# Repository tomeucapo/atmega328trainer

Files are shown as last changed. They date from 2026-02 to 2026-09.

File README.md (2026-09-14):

# ATMega328P Trainer

Basic board for practicing with the ATMega328P microcontroller. It includes an optocoupled input designed to connect pulse sensors at different voltages, such as an anemometer that operates at 24VDC. It also includes a USB-to-serial adapter that allows you to work with the ATMega's UART.

https://www.pcbway.com/project/shareproject/Anemometer_with_ATMega128P_fbefd825.html

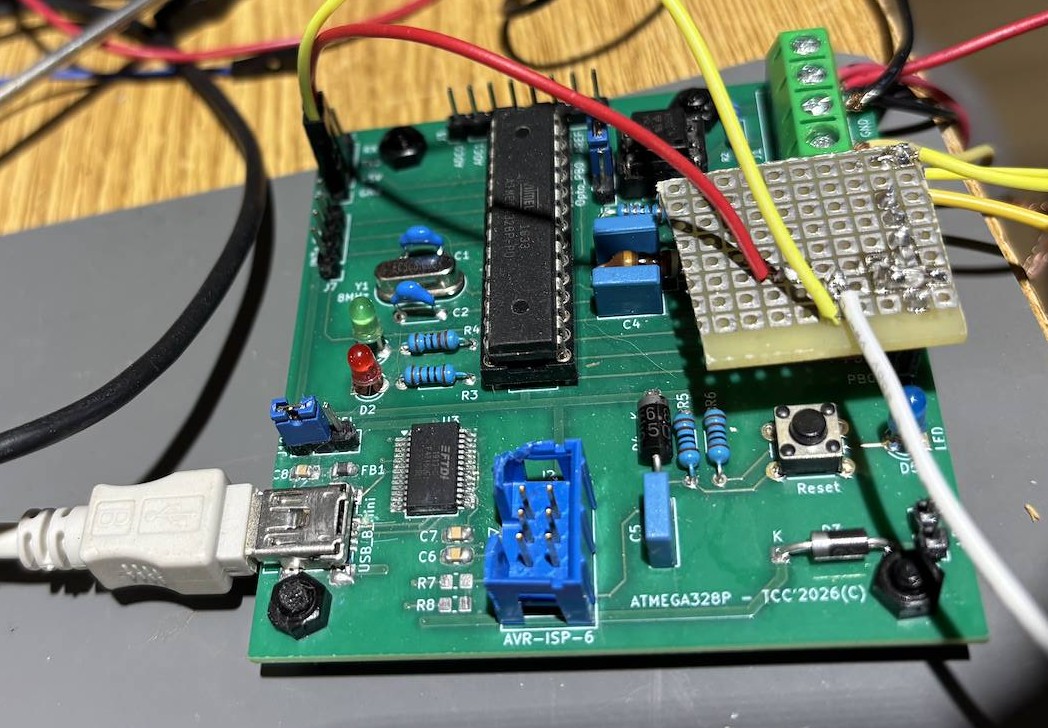
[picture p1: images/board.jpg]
Board


## Weather station base

This first version supports wind, rain and temperature sensors can read from USB port with simple commands:

```
@STAT_TEMP
@STAT_RAIN
@STAT_ANEMO
```

Also can reset RAIN counter with @RESET_RAIN.

Temperature sensor is digital serial sensor DS18B20, one bit data serial contected to PB2 port.

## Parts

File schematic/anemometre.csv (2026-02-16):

Reference | Qty | Value | DNP | Exclude from BOM | Exclude from Board | Footprint | Datasheet | MPN | Farnell | Farell
C1,C2 | 2 | 33pF |  |  |  | Capacitor_THT:C_Disc_D4.3mm_W1.9mm_P5.00mm | ~ |  | 4143719
C3,C4,C5 | 3 | 100nF |  |  |  | Capacitor_THT:C_Disc_D7.0mm_W2.5mm_P5.00mm | ~ | CK05BX104K | 1740547
C6,C7,C8 | 3 | 100nF |  |  |  | Capacitor_SMD:C_0805_2012Metric_Pad1.18x1.45mm_HandSolder | ~ | MC0805B104M160CT | 1708714
D1,D2,D5 | 3 | LED |  |  |  | LED_THT:LED_D3.0mm | ~ |  | 2251291,2984088,3777906
D3 | 1 | 1N5819 |  |  |  | Diode_THT:D_DO-35_SOD27_P10.16mm_Horizontal | http://www.vishay.com/docs/88503/1n4001.pdf | 1N5819 | 2677422
D4 | 1 | P6KE6.8A |  |  |  | Diode_THT:D_DO-35_SOD27_P10.16mm_Horizontal | http://www.vishay.com/docs/88503/1n4001.pdf | P6KE6.8A | 3288608
FB1 | 1 | 33 µH, 2.2 ohm |  |  |  | Inductor_SMD:L_0805_2012Metric | ~ | MLF1608C330KTD25 | 3648165
J1 | 1 | Anemometre |  |  |  | TerminalBlock_Phoenix:TerminalBlock_Phoenix_MKDS-1,5-4-5.08_1x04_P5.08mm_Horizontal | ~
J2 | 1 | AVR-ISP-6 |  |  |  | Connector_IDC:IDC-Header_2x03_P2.54mm_Vertical | ~ | 75869-131LF | 2293757
J3 | 1 | PORT_C_ADC |  |  |  | Connector_PinHeader_2.54mm:PinHeader_1x08_P2.54mm_Vertical | ~
J4 | 1 | PORT_B |  |  |  | Connector_PinHeader_2.54mm:PinHeader_1x06_P2.54mm_Vertical | ~
J5 | 1 | Opto_PB0 |  |  |  | Connector_PinHeader_2.54mm:PinHeader_1x03_P2.54mm_Vertical | ~
J6 | 1 | TTL Serial |  |  |  | Connector_PinHeader_2.54mm:PinHeader_1x04_P2.54mm_Vertical | ~
J7 | 1 | INTs/Ts |  |  |  | Connector_PinHeader_2.54mm:PinHeader_1x04_P2.54mm_Vertical | ~
J8 | 1 | USB_B_Mini |  |  |  | Connector_USB:USB_Mini-B_Wuerth_65100516121_Horizontal | ~ | 10033526N3212LF | 2813789
J9 | 1 | +5VDC |  |  |  | Connector_PinHeader_2.54mm:PinHeader_1x02_P2.54mm_Vertical | ~
J10 | 1 | PWR_SEL |  |  |  | Connector_PinHeader_2.54mm:PinHeader_1x03_P2.54mm_Vertical | ~
L1 | 1 | 10uH |  |  |  | Inductor_THT:L_Axial_L5.3mm_D2.2mm_P10.16mm_Horizontal_Vishay_IM-1 | ~ | 77F100K-TR-RC | 2924990
R1 | 1 | 10K |  |  |  | Resistor_THT:R_Axial_DIN0204_L3.6mm_D1.6mm_P7.62mm_Horizontal | ~ |  | 9339060
R2 | 1 | 4.7K |  |  |  | Resistor_THT:R_Axial_DIN0204_L3.6mm_D1.6mm_P7.62mm_Horizontal | ~ |  | 9339540
R3,R4,R5,R6 | 4 | 1K |  |  |  | Resistor_THT:R_Axial_DIN0204_L3.6mm_D1.6mm_P7.62mm_Horizontal | ~ |  | 9339051
R7,R8 | 2 | 100_NM |  |  |  | Resistor_SMD:R_0805_2012Metric_Pad1.20x1.40mm_HandSolder | ~
SW1 | 1 | Reset |  |  |  | Button_Switch_THT:SW_PUSH_6mm_H5mm | ~
U1 | 1 | ATmega328P-P |  |  |  | Package_DIP:DIP-28_W7.62mm | http://ww1.microchip.com/downloads/en/DeviceDoc/ATmega328_P%20AVR%20MCU%20with%20picoPower%20Technology%20Data%20Sheet%2040001984A.pdf | ATMEGA328P-PU | 1715487
U2 | 1 | 4N25 |  |  |  | Package_DIP:DIP-6_W7.62mm | https://www.vishay.com/docs/83725/4n25.pdf | CNY75A | 1045402
U3 | 1 | FT232RL |  |  |  | Package_SO:SSOP-28_5.3x10.2mm_P0.65mm | https://www.ftdichip.com/Support/Documents/DataSheets/ICs/DS_FT232R.pdf | FT232RL-REEL | 1146032
Y1 | 1 | 8MHz |  |  |  | Crystal:Crystal_HC49-U_Vertical | ~ | ECS-080-20-4X-DU | 4076777

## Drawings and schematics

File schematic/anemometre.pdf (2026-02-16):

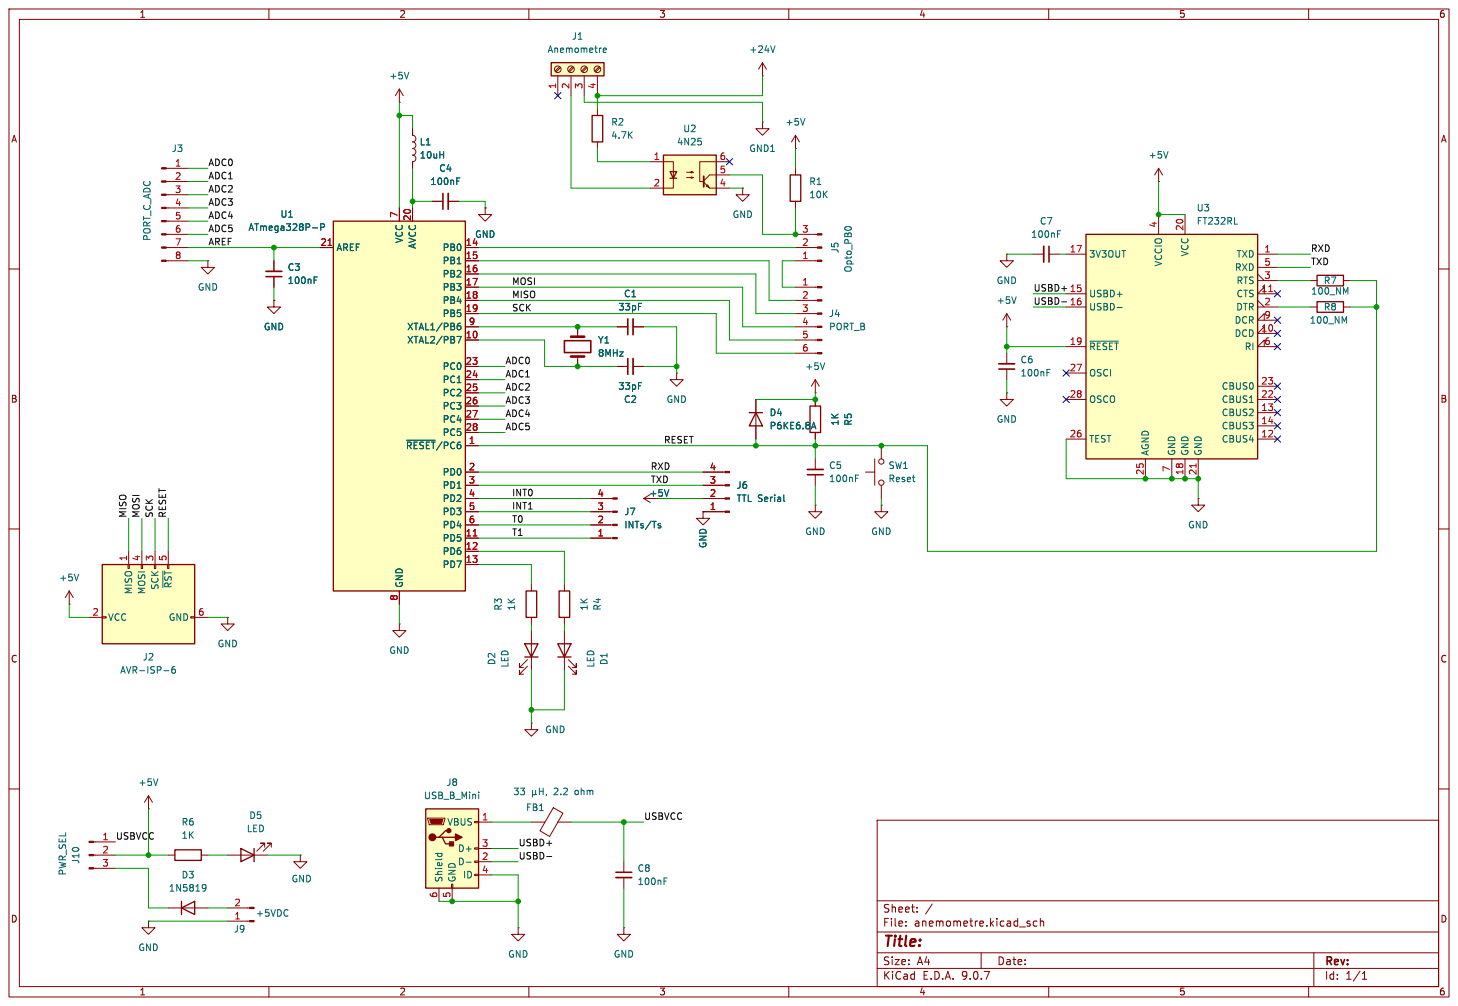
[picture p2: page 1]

7 VCC 20 GND 18 GND 21 TXD 1 RXD 5 RTS 3 CTS 11 DTR 2 DCR 9 DCD 10 RI 6 CBUS0 23 CBUS1 22 CBUS2 13 CBUS3 14 CBUS4 12 U3 FT232RL R3 1K

Id: 1/1 Title: File: anemometre.kicad_sch Sheet: /

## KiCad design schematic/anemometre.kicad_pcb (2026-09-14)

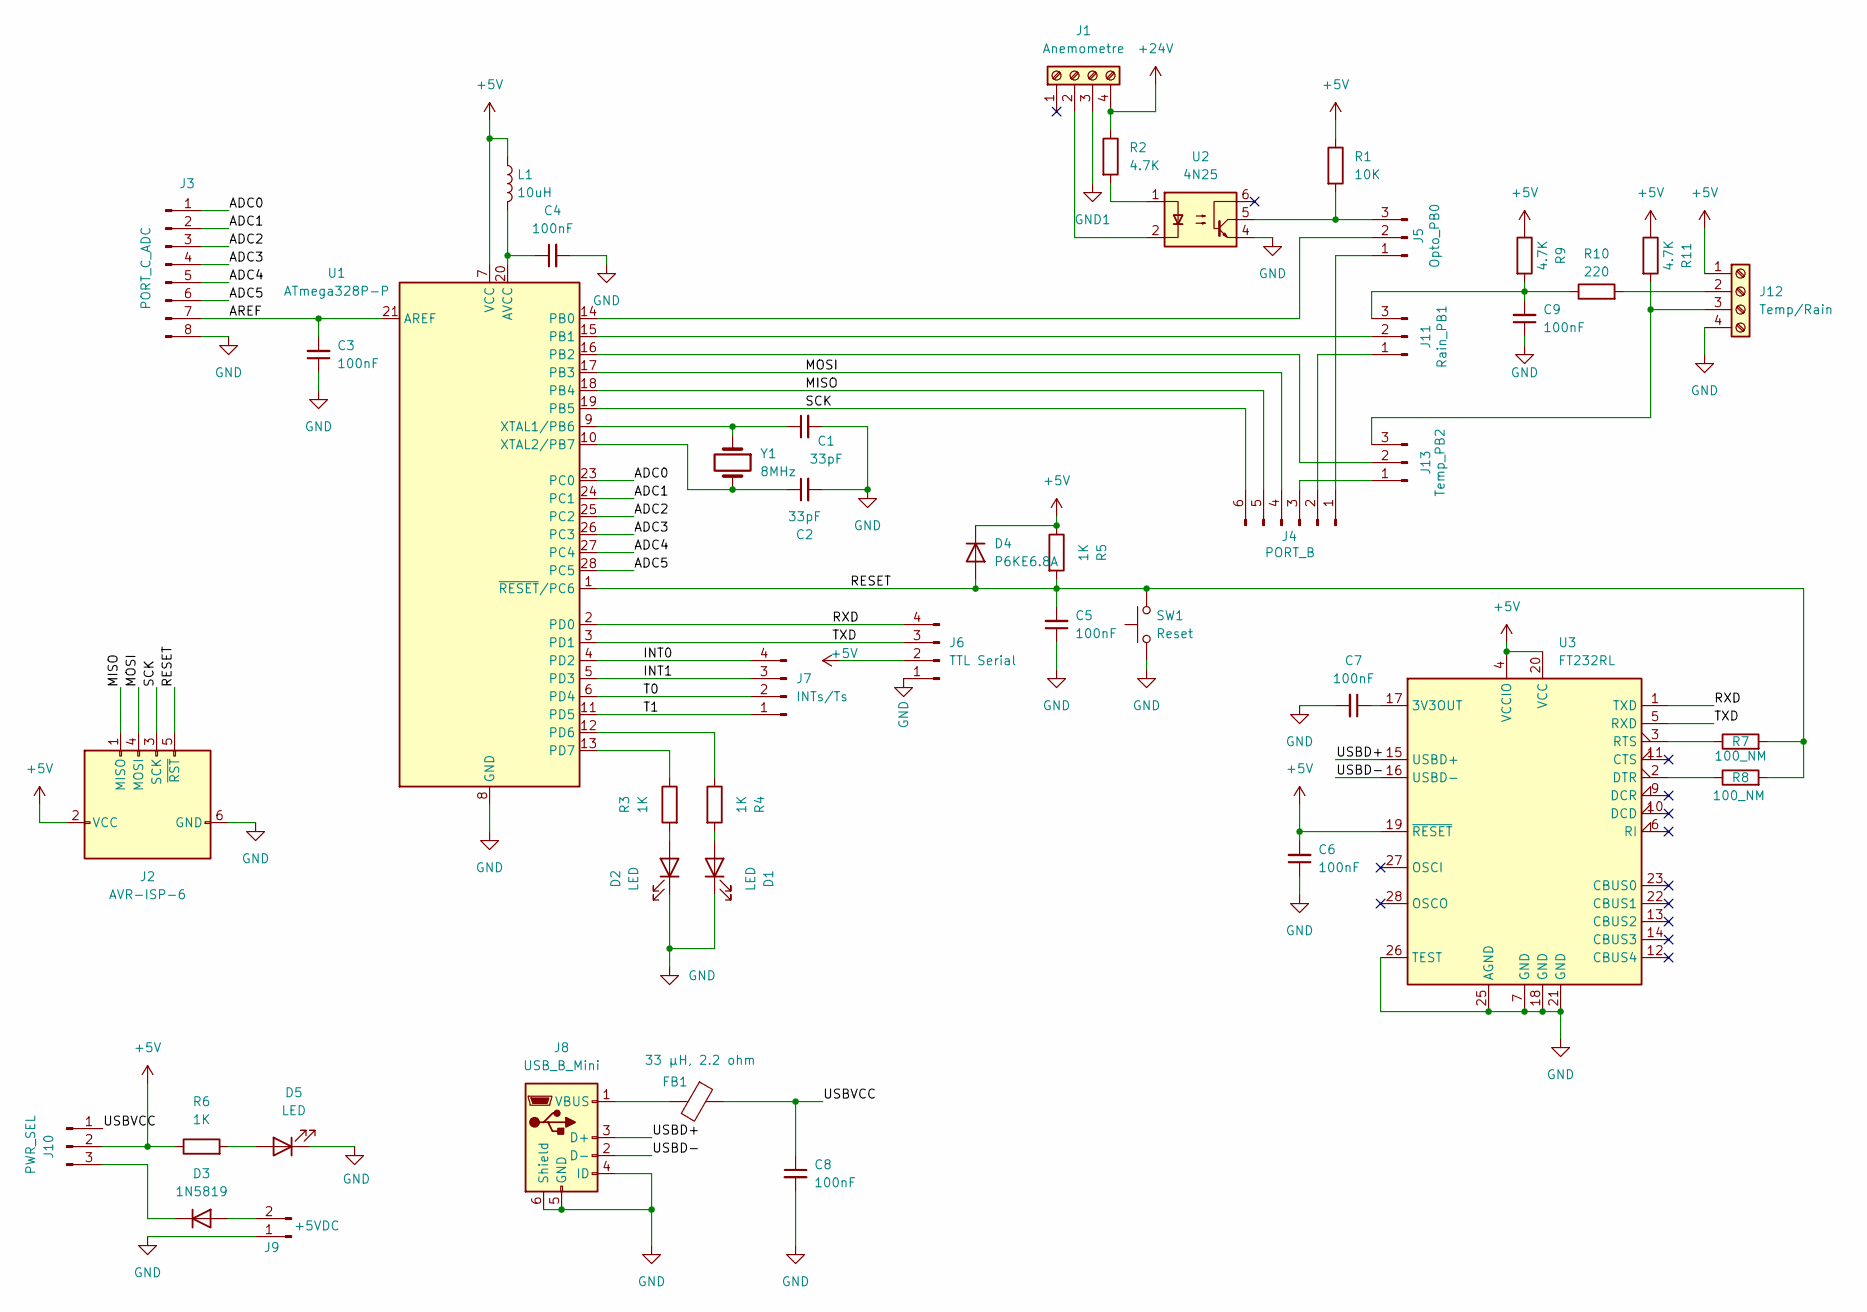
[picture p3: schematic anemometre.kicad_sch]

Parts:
C1, C2: 33pF; C_Disc_D4.3mm_W1.9mm_P5.00mm; Farnell 4143719
C3, C4: 100nF; C_Disc_D7.0mm_W2.5mm_P5.00mm; MPN CK05BX104K; Farnell 1740547
C5, C9: 100nF; C_Disc_D7.0mm_W2.5mm_P5.00mm
C6, C7, C8: 100nF; C_0805_2012Metric_Pad1.18x1.45mm_HandSolder; MPN MC0805B104M160CT; Farnell 1708714
D1: LED; LED_D3.0mm; Farnell 2984088
D2: LED; LED_D3.0mm; Farnell 3777906
D3: 1N5819; D_DO-35_SOD27_P10.16mm_Horizontal; MPN 1N5819; Farnell 2677422
D4: P6KE6.8A; D_DO-35_SOD27_P10.16mm_Horizontal; MPN P6KE6.8A; Farnell 3288608
D5: LED; LED_D3.0mm; Farnell 2251291
FB1: 33 µH, 2.2 ohm; L_0805_2012Metric; MPN MLF1608C330KTD25; Farnell 3648165
J1: Anemometre; TerminalBlock_Phoenix_MKDS-1,5-4-5.08_1x04_P5.08mm_Horizont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
J2: AVR-ISP-6; IDC-Header_2x03_P2.54mm_Vertical; MPN 75869-131LF; Farnell 2293757
J3: PORT_C_ADC; PinHeader_1x08_P2.54mm_Vertical
J4: PORT_B; PinHeader_1x06_P2.54mm_Vertical
J5: Opto_PB0; PinHeader_1x03_P2.54mm_Vertical
J6: TTL Serial; PinHeader_1x04_P2.54mm_Vertical
J7: INTs/Ts; PinHeader_1x04_P2.54mm_Vertical
J8: USB_B_Mini; USB_Mini-B_Wuerth_65100516121_Horizontal; MPN 10033526N3212LF; Farnell 2813789
J9: +5VDC; PinHeader_1x02_P2.54mm_Vertical
J10: PWR_SEL; PinHeader_1x03_P2.54mm_Vertical
J11: Rain_PB1; PinHeader_1x03_P2.54mm_Vertical
J12: Temp/Rain; TerminalBlock_Phoenix_MKDS-1,5-4-5.08_1x04_P5.08mm_Horizont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
J13: Temp_PB2; PinHeader_1x03_P2.54mm_Vertical
L1: 10uH; L_Axial_L5.3mm_D2.2mm_P10.16mm_Horizontal_Vishay_IM-1; MPN 77F100K-TR-RC; Farnell 2924990
R1: 10K; R_Axial_DIN0204_L3.6mm_D1.6mm_P7.62mm_Horizontal; Farnell 9339060
R2: 4.7K; R_Axial_DIN0204_L3.6mm_D1.6mm_P7.62mm_Horizontal; Farnell 9339540
R3, R4, R6: 1K; R_Axial_DIN0204_L3.6mm_D1.6mm_P7.62mm_Horizontal; Farnell 9339051
R5: 1K; R_Axial_DIN0204_L3.6mm_D1.6mm_P7.62mm_Horizontal
R7, R8: 100_NM; R_0805_2012Metric_Pad1.20x1.40mm_HandSolder
R9, R11: 4.7K; R_Axial_DIN0204_L3.6mm_D1.6mm_P7.62mm_Horizontal
R10: 220; R_Axial_DIN0204_L3.6mm_D1.6mm_P7.62mm_Horizontal
SW1: Reset; SW_PUSH_6mm_H5mm
U1: ATmega328P-P; DIP-28_W7.62mm; MPN ATMEGA328P-PU; Farnell 1715487
U2: 4N25; DIP-6_W7.62mm; MPN CNY75A; Farnell 1045402
U3: FT232RL; SSOP-28_5.3x10.2mm_P0.65mm; MPN FT232RL-REEL; Farnell 1146032
Y1: 8MHz; Crystal_HC49-U_Vertical; MPN ECS-080-20-4X-DU; Farnell 4076777

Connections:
+5V: C6.2, D4.1 (K), J2.2 (VCC), J6.2, J10.2, J12.1, L1.1, R1.1, R5.1, R6.1, R9.1, R11.1, U1.7 (VCC), U3.4 (VCCIO), U3.19 (~RESET), U3.20 (VCC)
+24V: J1.4, R2.1
/ADC0: J3.1, U1.23 (PC0)
/ADC1: J3.2, U1.24 (PC1)
/ADC2: J3.3, U1.25 (PC2)
/ADC3: J3.4, U1.26 (PC3)
/ADC4: J3.5, U1.27 (PC4)
/ADC5: J3.6, U1.28 (PC5)
/AREF: C3.2, J3.7, U1.21 (AREF)
/INT0: J7.4, U1.4 (PD2)
/INT1: J7.3, U1.5 (PD3)
/MISO: J2.1 (MISO), J4.5, U1.18 (PB4)
/MOSI: J2.4 (MOSI), J4.4, U1.17 (PB3)
/RESET: C5.2, D4.2 (A), J2.5 (~RST), R5.2, R7.2, R8.2, SW1.2, U1.1 (~RESET/PC6)
/RXD: J6.4, U1.2 (PD0), U3.1 (TXD)
/SCK: J2.3 (SCK), J4.6, U1.19 (PB5)
/T0: J7.2, U1.6 (PD4)
/T1: J7.1, U1.11 (PD5)
/TXD: J6.3, U1.3 (PD1), U3.5 (RXD)
/USBD+: J8.3 (D+), U3.15 (USBD+)
/USBD-: J8.2 (D-), U3.16 (USBD-)
/USBVCC: C8.1, FB1.1, J10.1
GND: C1.2, C2.2, C3.1, C4.2, C5.1, C6.1, C7.2, C8.2, C9.1, D1.1 (K), D2.1 (K), D5.1 (K), J2.6 (GND), J3.8, J6.1, J8.4 (ID), J8.5 (GND), J8.6 (Shield), J9.1, J12.4, SW1.1, U1.8 (GND), U1.22 (GND), U2.4, U3.7 (GND), U3.18 (GND), U3.21 (GND), U3.25 (AGND), U3.26 (TEST)
GND1: J1.3
unnamed: D1.2 (A), R4.2
unnamed: D2.2 (A), R3.2
unnamed: D3.2 (A), J9.2
unnamed: D3.1 (K), J10.3
unnamed: D5.2 (A), R6.2
unnamed: J1.2, U2.2
unnamed: J4.1, J5.1
unnamed: J5.2, U1.14 (PB0)
unnamed: J5.3, R1.2, U2.5
unnamed: FB1.2, J8.1 (VBUS)
unnamed: J4.2, J11.1
unnamed: J11.2, U1.15 (PB1)
unnamed: C9.2, J11.3, R9.2, R10.1
unnamed: J12.2, R10.2
unnamed: J12.3, J13.3, R11.2
unnamed: J4.3, J13.1
unnamed: J13.2, U1.16 (PB2)
unnamed: R2.2, U2.1
unnamed: C4.1, L1.2, U1.20 (AVCC)
unnamed: R4.1, U1.12 (PD6)
unnamed: R3.1, U1.13 (PD7)
unnamed: C1.1, U1.9 (XTAL1/PB6), Y1.1
unnamed: C2.1, U1.10 (XTAL2/PB7), Y1.2
unnamed: C7.1, U3.17 (3V3OUT)
unnamed: R8.1, U3.2 (DTR)
unnamed: R7.1, U3.3 (RTS)

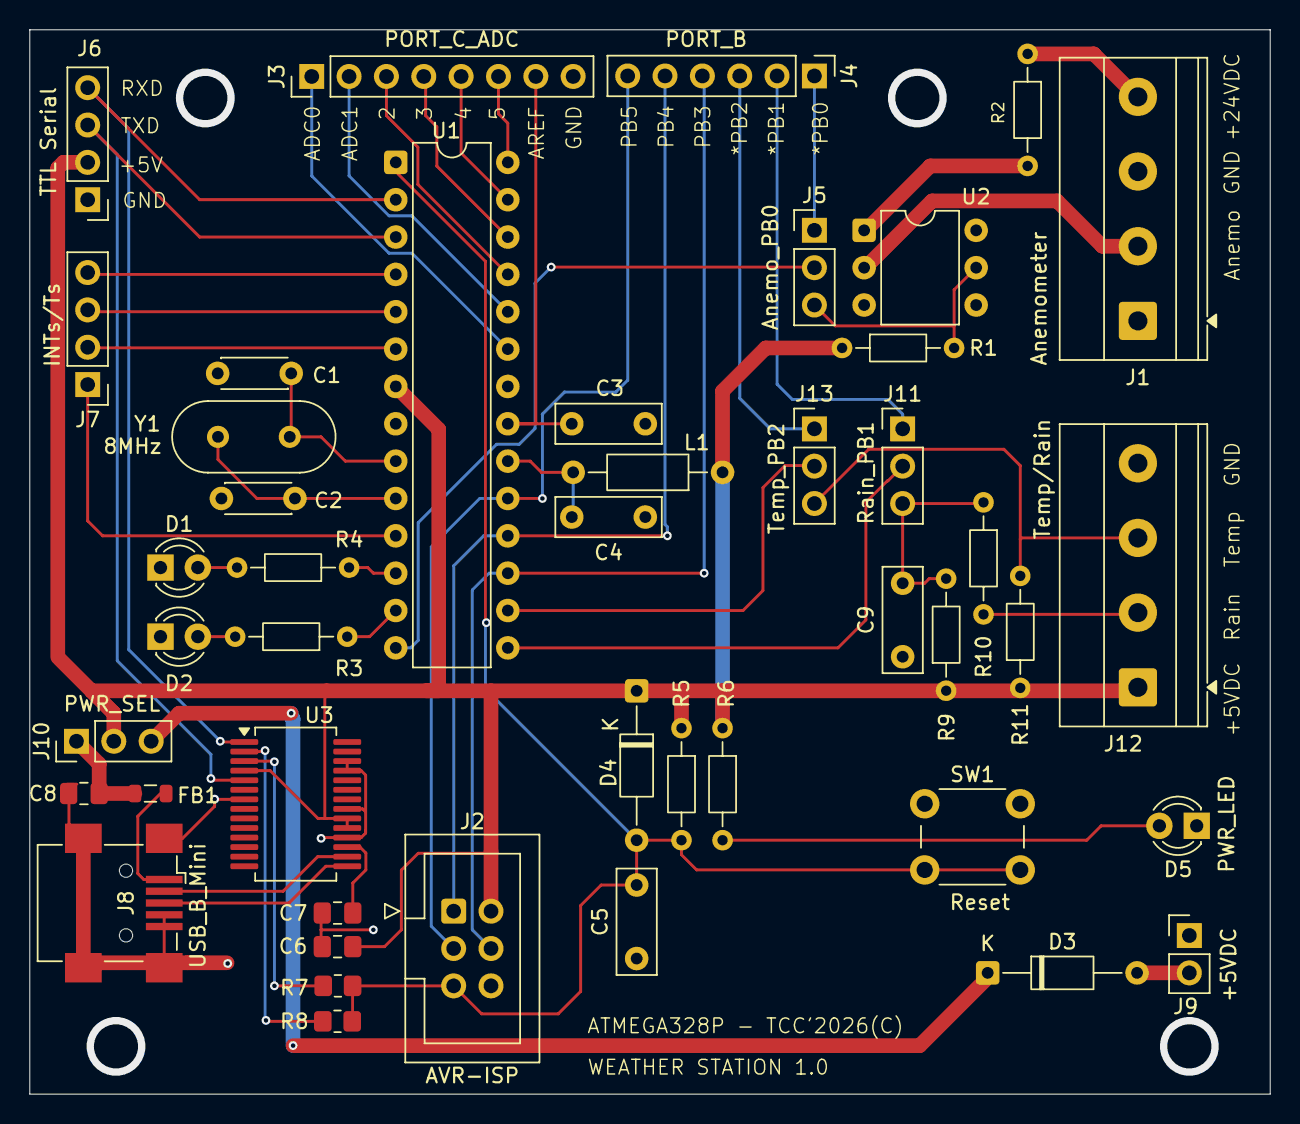
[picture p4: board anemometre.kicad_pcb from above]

Board: 2 copper layers, 84.4 x 72.4 mm, 45 parts (0 on the bottom side), 49 nets.

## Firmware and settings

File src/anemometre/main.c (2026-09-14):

#ifndef F_CPU
#define F_CPU 8000000UL
#endif

#include <avr/io.h>
#include <avr/interrupt.h>
#include <compat/deprecated.h>
#include <stdlib.h>
#include <string.h>
#include <stdint.h>
#include "ds18b20.h"

// ======================================================
// CONFIG
// ======================================================

#define BAUD 9600
#define UBRR_VALUE ((F_CPU/16/BAUD)-1)

#define FACTOR_KMH 3.2f
#define MIN_PERIOD 100
#define MAX_OVERFLOWS_NO_SIGNAL 5
#define RAIN_DEBOUNCE_MS 100
#define RAIN_MM_PER_TIP 0.3f

// ======================================================
// ANEMOMETRO
// ======================================================

volatile uint16_t last_capture = 0;
volatile uint16_t period = 0;

volatile uint8_t new_data = 0;
volatile uint8_t overflow_counter = 0;

float velocidad = 0;

// ======================================================
// PLUVIOMETRO
// ======================================================

volatile uint32_t rain_count = 0;
volatile uint32_t rain_last_pulse = 0;

// ======================================================
// TIMER MILLISECONDS
// ======================================================

volatile uint32_t millis_counter = 0;

// ======================================================
// UART
// ======================================================

void uart_init(void)
{
    UBRR0H = (UBRR_VALUE >> 8);
    UBRR0L = UBRR_VALUE;

    UCSR0B = (1<<RXEN0) | (1<<TXEN0);
    UCSR0C = (1<<UCSZ01) | (1<<UCSZ00);
}

void uart_tx_char(char c)
{
    while(!(UCSR0A & (1<<UDRE0)));
    UDR0 = c;
}

void uart_tx_string(const char* s)
{
    while(*s)
        uart_tx_char(*s++);
}

uint8_t uart_rx_available(void)
{
    return (UCSR0A & (1<<RXC0));
}

// ======================================================
// TIMER1 INPUT CAPTURE (ANEMOMETRO)
// ======================================================

void timer1_init(void)
{
    DDRB &= ~(1<<DDB0);

    TCCR1A = 0;

    TCCR1B =
        (1<<ICNC1) |
        (1<<ICES1) |
        (1<<CS11);

    TIMSK1 =
        (1<<ICIE1) |
        (1<<TOIE1);
}

ISR(TIMER1_CAPT_vect)
{
    uint16_t capture = ICR1;
    uint16_t diff = capture - last_capture;

    last_capture = capture;

    if(diff > MIN_PERIOD)
    {
        period = diff;
        new_data = 1;
        overflow_counter = 0;
    }
}

ISR(TIMER1_OVF_vect)
{
    overflow_counter++;
}

// ======================================================
// TIMER0 1 ms
// ======================================================

void timer0_init(void)
{
    TCCR0A = (1<<WGM01);

    OCR0A = 124;

    TCCR0B =
        (1<<CS01) |
        (1<<CS00);

    TIMSK0 = (1<<OCIE0A);
}

ISR(TIMER0_COMPA_vect)
{  
    static uint16_t blink_counter = 0;

    millis_counter++;

    if(++blink_counter >= 500)
    {
        PORTD ^= (1<<PORTD6);
        blink_counter = 0;
    }
}

// ======================================================
// PLUVIOMETRO
// PB1 = PCINT1
// CONTACTO NC
// ======================================================

void rain_init(void)
{
    DDRB &= ~(1<<DDB1);
    PORTB |= (1<<PORTB1);
    PCICR |= (1<<PCIE0);
    PCMSK0 |= (1<<PCINT1);
}

ISR(PCINT0_vect)
{
    static uint8_t old_state = 0;

    uint8_t new_state = (PINB & (1<<PINB1)) ? 1 : 0;

    // NC -> contar apertura

    if(!old_state && new_state)
    {
        uint32_t now = millis_counter;

        if((now - rain_last_pulse) > RAIN_DEBOUNCE_MS)
        {
            rain_count++;
            rain_last_pulse = now;
        }
    }

    old_state = new_state;
}

void calculate_anemo_velocity()
{
        if(overflow_counter > MAX_OVERFLOWS_NO_SIGNAL)
            velocidad = 0;
        
        if(!new_data)
            return;
        
        float frequency = 0;
        uint16_t local_period;

        cli();
        local_period = period;
        new_data = 0;
        sei();

        if(local_period != 0)
        {
           frequency = 100000.0f / local_period;
           velocidad = frequency * FACTOR_KMH;
        }
}


// ======================================================
// IO
// ======================================================

void io_init(void)
{
    DDRD = (1<<DDD5) | (1<<DDD6) | (1<<DDD7);
}

// ======================================================
// MAIN
// ======================================================

int main(void)
{
    io_init();
    uart_init();
    timer1_init();
    timer0_init();
    rain_init();
    ds18b20_init();

    sei();


    char buffer[32];
    char rx_buffer[32];
    uint8_t rx_index = 0;

    uart_tx_string("*** ATMEGA328P WEATHER 1.0\r\n");


    while(1)
    {
        // ====================================
        // ANEMOMETRO
        // ====================================

        calculate_anemo_velocity();

        // ====================================
        // SERIAL COMMANDS
        // ====================================

        while(uart_rx_available())
        {
            char c = UDR0;

			uart_tx_char(c);

            if(c == '\r' || c == '\n')
            {
                rx_buffer[rx_index] = 0;
                rx_index = 0;

                if(strcmp(rx_buffer,"@STAT_ANEMO") == 0)
                {
                    dtostrf(velocidad,6,3,buffer);

                    uart_tx_string("ANEMO=");
                    uart_tx_string(buffer);
                    uart_tx_string(" km/h\r\n");
                }
                else if(strcmp(rx_buffer,"@STAT_RAIN") == 0)
                {
                    uint32_t count;
                    float mm;

                    cli();
                    count = rain_count;
                    sei();
                    mm = count * RAIN_MM_PER_TIP;

                    uart_tx_string("RAIN_COUNT=");

                    ultoa(count,buffer,10);
                    uart_tx_string(buffer);

                    uart_tx_string("\r\n");

                    uart_tx_string("RAIN_MM=");

                    dtostrf(mm,6,2,buffer);
                    uart_tx_string(buffer);

                    uart_tx_string("\r\n");

                    uart_tx_string("RAIN_LM2=");

                    dtostrf(mm,6,2,buffer);
                    uart_tx_string(buffer);

                    uart_tx_string("\r\n");
                }
                else if(strcmp(rx_buffer,"@STAT_TEMP") == 0)
                {
                    float temp = ds18b20_get_temp();

                    if(temp == DS18B20_ERROR_TEMP)
                    {
                        uart_tx_string("TEMP_ERR\r\n");
                    }
                    else
                    {
                        uart_tx_string("TEMP=");
                        dtostrf(temp,6,3,buffer);
                        uart_tx_string(buffer);
                        uart_tx_string(" C\r\n");
                    }
                }
                else if(strcmp(rx_buffer,"@RESET_RAIN") == 0)
                {
                    cli();
                    rain_count = 0;
                    sei();

                    uart_tx_string("RAIN RESET OK\r\n");
                }
                else
                {
                    uart_tx_string("ERR\r\n");
                }
            }
            else
            {
                if(rx_index < sizeof(rx_buffer)-1)
                {
                    rx_buffer[rx_index++] = c;
                }
            }
        }
    }
}

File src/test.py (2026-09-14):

#!/usr/bin/env python3

import re
import time
import serial

PORT = "/dev/ttyUSB0"

ser = serial.Serial(
    port=PORT,
    baudrate=9600,
    bytesize=serial.EIGHTBITS,
    parity=serial.PARITY_NONE,
    stopbits=serial.STOPBITS_ONE,
    timeout=2,
    xonxoff=False,
    rtscts=False,
    dsrdtr=False
)


def send_command(cmd):
    """Envía un comando y devuelve las líneas recibidas."""

    ser.reset_input_buffer()
    ser.write((cmd + "\r\n").encode())

    lines = []

    while True:
        line = ser.readline().decode("ascii", errors="ignore").strip()

        if not line:
            break

        lines.append(line)

    return lines


def get_anemo():
    lines = send_command("@STAT_ANEMO")

    for line in lines:
        m = re.search(r"ANEMO=([0-9.]+)", line)
        if m:
            return float(m.group(1))

    return 0

def get_temp():
    lines = send_command("@STAT_TEMP")

    for line in lines:
        m = re.search(r"TEMP=([0-9.]+)", line)
        if m:
            return float(m.group(1))

    return 0

def get_rain():
    lines = send_command("@STAT_RAIN")

    data = {
        "count": 0,
        "mm": 0.0,
        "lm2": 0.0
    }

    for line in lines:

        if line.startswith("RAIN_COUNT="):
            data["count"] = int(line.split("=")[1])

        elif line.startswith("RAIN_MM="):
            data["mm"] = float(line.split("=")[1])

        elif line.startswith("RAIN_LM2="):
            data["lm2"] = float(line.split("=")[1])

    return data


try:
    send_command("@RESET_RAIN")

    while True:

        viento = get_anemo()
        lluvia = get_rain()
        temp = get_temp()

        ts = time.strftime("%Y-%m-%d %H:%M:%S")
        print(f"{ts}\t{viento}\t{lluvia['lm2']}\t{temp} C")

        #print(f"Viento : {viento} km/h")
        #print(f"Lluvia : {lluvia['count']} pulsos")
        #print(f"Rain mm: {lluvia['mm']}")
        #print(f"Rain L/m²: {lluvia['lm2']}")

        time.sleep(2)

except KeyboardInterrupt:
    print("\nFinalizando...")

finally:
    ser.close()

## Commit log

2026-02-16 Initial schematics push
    [anemometre-B_Cu.gbr, anemometre-B_Mask.gbr, anemometre-B_Paste.gbr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]
2026-08-25 latest modifications and add raincounter sensor
    [anemometre-B_Cu.gbr, anemometre-B_Mask.gbr, anemometre-B_Paste.gbr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]
2026-08-25 Add status led bilinking
2026-08-25 Moved led blinking on TIMER0 ISR
2026-08-25 Improved led blinking code
2026-09-10 Added DS18B20 temperature sensor
2026-09-10 Solved some typo and include issues
    [main.c]
2026-09-11 Upload photo of final board
2026-09-11 Update README with weather station details
    Added information about the weather station base and its sensor support.
2026-09-14 Schematic and PCB upgraded to support temperature and rain sensors
    [anemometre.kicad_pcb, anemometre.kicad_sch]
2026-09-14 Added temperature and rain sensors support to schematic and pcb
2026-09-17 Add cooperative scheduler, interrupt-driven UART and SSD1306 driver
    Split the UART and SSD1306 code into their own modules. Refactored
    main loop into periodic tasks handled by a small cooperative
    scheduler (1 ms tick from TIMER0). UART RX is now interrupt-driven
    with a 128-byte ring buffer.
2026-09-18 Created I2C IO Expansion board
2026-10-15 Added i2c eeprom support for local logging storage
2026-10-15 Print run time on screen
2026-10-15 Changed twi return value for eeprom i2c
2026-10-15 Latest i2c eeprom improvements
2026-10-16 Moved some functions to uart module
2026-10-16 Latest shcematic of IOExtesion board and latest Gerbers
2026-10-19 Refactored some repeated code and first temperature graph on OLED
2026-10-23 Added MCP detection message and led blink for MCP I2C IC
2026-10-23 Latest schematic of IOExtension modifications
2026-10-29 Create new board for lora sensors support and BME 280 temp and preasure sensor
2026-11-09 Latest modifications on code and lora board schematics
2026-11-11 Patch on BME280 code to calibrate
2026-11-11 Latest changes on lora remote schematic and PCB and patch on main firmware
